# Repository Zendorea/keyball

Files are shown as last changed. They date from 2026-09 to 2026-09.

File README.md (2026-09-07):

# Keyball61 Wireless (PMW3610 / nice!nano / ZMK)

A fork of [Yowkees/keyball](https://github.com/Yowkees/keyball) for converting a
**Keyball61** (holykeebs Keyball61 rev2) to a **fully wireless** build:
**nice!nano v2 + ZMK**, with the power-hungry PMW3360 trackball sensor replaced by
the low-power **PMW3610**.

This fork holds the **hardware** side of that conversion — the custom PMW3610
sensor daughterboard. The **firmware** (ZMK) lives in a separate repo.

## What's here

- **[`keyball61_wireless/pmw3610_daughterboard/`](keyball61_wireless/pmw3610_daughterboard/)**
  — the PMW3610 trackball daughterboard: KiCad source, reproducible build
  pipeline, DRC-clean gerbers (ordered from PCBway), BOM, and full design notes.
  A drop-in replacement for the stock Keyball61 ball-reader board that keeps the
  original 7-pin connector and adds a MOTION interrupt line. **See its README.**
- **`keyball61/`** — the upstream Yowkees Keyball61 hardware design data (kept for
  reference: case, PCB, dimensions the daughterboard indexes to).

## Firmware (separate repo)

The wireless ZMK config is **`zmk-config-keyball61-wireless`** (standalone, as ZMK
configs must be). Trackball on `&spi1`: SCK P1.13, SDIO P0.10 (3-wire), CS P0.09,
MOTION P1.11, 2 MHz — based on the proven `tangbonze/zmk-config-Keyball61`.

## Project status

- ✅ Daughterboard: designed, DRC-clean, gerbers ordered (PCBway, ENIG, 1.0 mm)
- ✅ Parts sourced: PMW3610+LM18-LSI (AliExpress), passives/LDO (LCSC), 34 mm ball
- ✅ ZMK config: built (separate repo)
- ⬜ Assemble + flash when hardware arrives
- ⬜ (optional) main-board fork: nice!nano + nice!view

## Credits

Base keyboard design © [Yowkees / Keyball](https://github.com/Yowkees/keyball)
(see `LICENSE`). PMW3610 reference designs: siderakb / badjeff. Kit: holykeebs.

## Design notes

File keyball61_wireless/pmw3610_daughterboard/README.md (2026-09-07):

# PMW3610 Trackball Daughterboard — Keyball61 Wireless

Drop-in replacement for the stock Keyball61 PMW3360 ball-reader board, redesigned
for the low-power **PMW3610** sensor on a **nice!nano / ZMK** wireless build.
Keeps the stock Keyball **7-pin** connector at the exact original positions (drops
into a stock Keyball main board) and adds a **separate MOTION solder hole** so ZMK
can run the sensor interrupt-driven for best battery life.

**Status: final, DRC-clean, gerbers ordered from PCBway.**

## Board summary
- **23.0 × 25.0 mm**, 2-layer, **1.0 mm**, ENIG. U-shaped outline with a lens slot
  open to the top edge, sized to the **LM18-LSI** lens body.
- **PMW3610 optical center** at the original ball-facing position; connector +
  sensor share the X=11.0 mm centerline (ball centers on the IC via the stock
  Keyball cage).
- **7-pin connector** (CK·IO·G·V·G·CS·RST) at exact stock 2.54 mm positions +
  a separate **MOT** solder hole on the same pitch.
- Full PMW3610 support: **TLV74318** 1.8 V LDO + charge-pump/decoupling caps +
  NRESET & MOTION pull-ups. Solid B.Cu GND pour with stitching vias.
- DRC: **0 unrouted / 0 unconnected / 0 electrical / 0 hole-clearance**
  (5 non-fatal courtyard-overlap advisories — not fab-blocking).

## Files
| File | What it is |
|---|---|
| `DESIGN.md` | Full design spec: optics Z-stack, connector, MOTION, datasheet notes. |
| `BOM.csv` | As-built bill of materials with LCSC part numbers + cap-to-pin mapping. |
| `pmw3610_daughterboard.kicad_pcb` / `.kicad_pro` | Final routed board + project. |
| `pmw3610_daughterboard.kicad_dru` | Custom design rules (0.15 mm edge clearance). |
| `pmw3610_kb.pretty/` | The 3 custom footprints used: PMW3610 (siderakb), 7-pin connector, MOTION pad. |
| `fp-lib-table` | Resolves the local footprint lib on open. |
| `gerbers/` + `pmw3610_daughterboard_gerbers.zip` | Fab package (PCBway-ready): 7 gerbers + separate PTH/NPTH Excellon drills. |
| `drc.json` | Latest DRC report. |
| `board_final.png` / `board_top.png` / `board_bot.png` | Renders. |

## Reproducible build pipeline (KiCad 10 pcbnew + Freerouting 2.4.1)
Run in order (system `python3` with `pcbnew`, except footprints which use kiutils):
```
make_footprints_v2.py   -> custom footprints (sensor, 7-pin conn, MOTION pad)
build_board_22x25.py    -> place + net + design rules
export_dsn.py           -> Specctra DSN
Freerouting (headless, -mt 1, --router.via_costs=30, -inc GND)
import_ses.py           -> import routed session
pour_gnd.py             -> B.Cu GND pour (solid pad connection)
finish_22x25.py         -> GND stitching vias; fill zones last
kicad-cli pcb drc / export gerbers,drill
```

## Parts sourcing
- **Sensor + lens:** PMW3610DM-**SUDU** + **LM18-LSI** as a SET on AliExpress
  (not stocked at LCSC/Digikey). Match the lens (LM18-LSI) — avoid the 3360/LM19.
- **Passives + LDO + header:** LCSC (see `BOM.csv` for exact part numbers).
- **Ball:** 34 mm (Perixx PERIPRO-303 / SANWA).

## Firmware
Wireless ZMK config lives in a separate repo (`zmk-config-keyball61-wireless`):
trackball on `&spi1` — SCK P1.13, SDIO P0.10 (3-wire), CS P0.09, MOTION P1.11,
2 MHz. See that repo's README.

## Verify before assembly
- Sensor/lens standoff vs your trackball housing (base-plate sets focus, not PCB thickness).
- Continuity-check the sensor pins (esp. SCLK) after soldering — the most common DIY failure.

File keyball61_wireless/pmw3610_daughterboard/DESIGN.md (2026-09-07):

# PMW3610 Trackball Daughterboard — Keyball61 Wireless (nice!nano / ZMK)

Purpose-built PMW3610 replacement for the stock Keyball61 PMW3360 ball-reader
board, for a nice!nano/ZMK wireless build (low power). Datasheet-faithful optical
mounting. DRC-clean.

## Final specs
- Outline: 23.0 x 25.0 mm (original 22x25 + 1mm on the right so the MOTION hole
  sits on the connector's 2.54mm pitch at full pad size). 1.0mm thick, 2-layer.
- Optics: lens slot open to the top edge, sized to the LM18-LSI lens body
  (8.25 x 12.9mm), between the sensor pin columns. No PCB lens-alignment hole:
  the LM18-LSI guide posts lock into the sensor package, not the PCB (per the
  PMW3610 datasheet Fig 5 and the siderakb/badjeff reference boards).
  PMW3610 sensor optical center at original ball-facing position.
- Connector: stock Keyball 7-pin (SCLK,SDIO,GND,VCC,GND,NCS,NRESET) at the EXACT
  original 2.54mm-pitch positions -> drops into a stock Keyball main board.
- MOTION: separate solder hole (MOT) on the same 2.54mm pitch as the connector,
  same 1.5mm pad / 0.9mm drill. Wire it to a spare nice!nano GPIO (P0.31) on the
  stock board, or route it as a trace on a forked main board.
- Full PMW3610 support circuit: TLV74318 1.8V LDO (U2) + charge-pump/decoupling
  caps + NRESET pull-up. All parts ABOVE the connector line (nothing fouls the
  90-degree main-board joint). GND ground plane on B.Cu.
- Placement per IPC-7351/Eurocircuits: 0603 >=2.8mm pitch, 0805 >=3.2mm.

## Datasheet Z-stack (PixArt, saved in ../../../pmw3610_datasheets/)
- Ball surface -> lens reference plane = 2.4mm typ (2.2/2.6 min/max), +/-0.2mm DOF.
- Ball surface -> sensor pin reference plane (PCB top copper) = 8.35mm typ.
- PCB thickness does NOT set focus (lens indexes to the pin plane); 1.0mm chosen
  for lens/ball clearance. Verify base-plate/housing standoff at assembly.

## Reproducible build pipeline (KiCad 10 pcbnew + Freerouting 2.4.1)
  make_footprints_v2.py  -> custom footprints (sensor, 7-pin conn, MOTION pad, lens)
  build_board_22x25.py   -> place + net + design rules (pcbnew)
  export_dsn.py          -> Specctra DSN
  Freerouting (headless, -mt 1, --router.via_costs=30, -inc GND for pour route)
  import_ses.py          -> import routed session
  pour_gnd.py            -> B.Cu GND pour (solid pad connection)
  finish_22x25.py        -> GND stitching vias; fill zones last
  kicad-cli pcb drc / export gerbers,drill

## DRC status
0 unrouted, 0 unconnected, 0 electrical violations. 5 courtyard_overlap
advisories remain (IPC keep-out for rework room, NOT fab-blocking; JLCPCB/PCBway
build fine). See board_final.png.

## Fab (PCBway)
2-layer, 1.0mm, ENIG, qty 5. Upload pmw3610_daughterboard_gerbers.zip.

## Verify before ordering
1. Sensor/lens standoff vs your trackball housing (base-plate sets focus).
2. Trackball connector CS/IRQ vs your holykeebs rev2 PCB silk (rev1≈rev2).

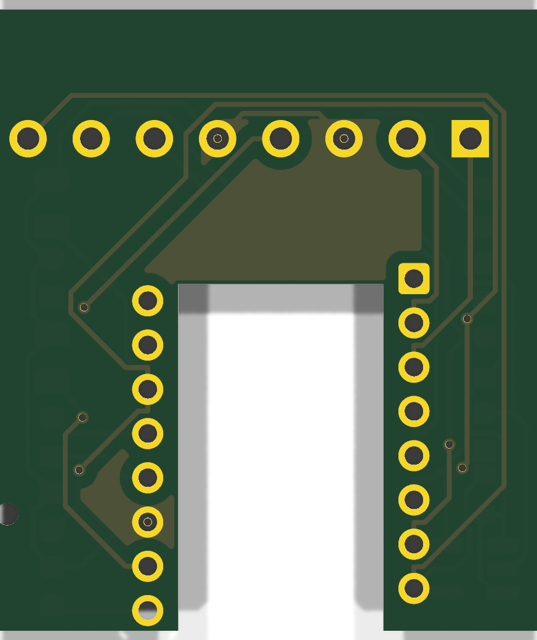
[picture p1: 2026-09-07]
keyball61_wireless/pmw3610_daughterboard/board_bot.png

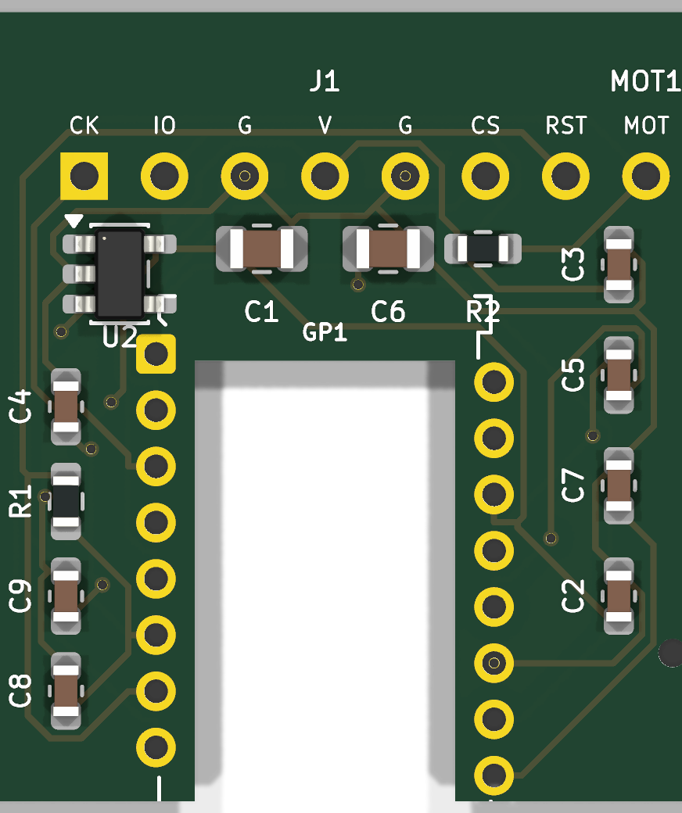
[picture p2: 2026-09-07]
keyball61_wireless/pmw3610_daughterboard/board_final.png

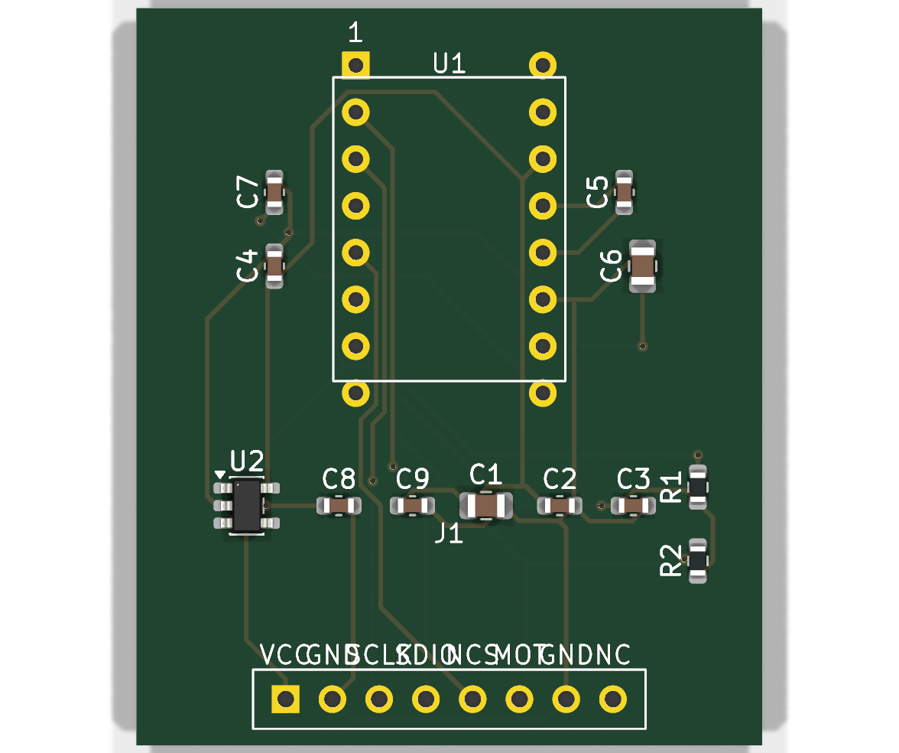
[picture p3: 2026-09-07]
keyball61_wireless/pmw3610_daughterboard/board_top.png

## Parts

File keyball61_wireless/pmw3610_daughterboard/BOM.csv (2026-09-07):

Ref | Value | Footprint | LCSC | Qty | Pin/Net | Notes
U1 | PMW3610DM-SUDU | pmw3610_kb:PMW3610DM-SUDU-siderakb |  | 1 | - | Optical sensor; buy as a SET with the LM18-LSI lens (AliExpress). Not stocked at LCSC/Digikey.
LENS | LM18-LSI | - |  | 1 | - | PixArt lens for PMW3610; bundled with U1.
U2 | TLV74318PDBVR | SOT-23-5 | C485152 | 1 | VCC->+1V8 | 1.8V fixed LDO (core rail).
C1 | 3.3uF/25V X5R | C_0603_1608Metric | C342962 | 1 | VDD (+1V8) | 1.8V core bulk reservoir.
C2 | 100nF X7R | C_0603_1608Metric | C14663 | 1 | VDD (+1V8) | 1.8V core HF decouple.
C3 | 100nF X7R | C_0603_1608Metric | C14663 | 1 | VDDIO (VCC) | I/O supply decouple.
C4 | 100nF X7R | C_0603_1608Metric | C14663 | 1 | VDD (+1V8) | Additional core decouple.
C5 | 10nF X7R | C_0603_1608Metric | C57112 | 1 | CP<->CN | Charge-pump flying cap.
C6 | 10uF X5R | C_0805_2012Metric | C15850 | 1 | PASS_T | Internal-regulator bypass reservoir.
C7 | 10nF X7R | C_0603_1608Metric | C57112 | 1 | VCP | Charge-pump output decouple.
C8 | 1uF/25V X7R | C_0603_1608Metric | C29936 | 1 | VCC (LDO IN) | LDO input cap.
C9 | 1uF/25V X7R | C_0603_1608Metric | C29936 | 1 | +1V8 (LDO OUT) | LDO output cap.
R1 | 10k | R_0603_1608Metric | C25804 | 1 | NRESET<->VCC | NRESET pull-up to 3.3V.
R2 | 10k | R_0603_1608Metric | C25804 | 1 | MOTION<->VCC | MOTION pull-up (populated; hardens the MOTION line alongside the nice!nano internal pull-up).
J1 | Conn_Keyball_7pin | pmw3610_kb:Conn_Keyball_7pin_stock |  | 1 | - | Stock Keyball 7-pin 2.54mm connector: CK/IO/G/V/G/CS/RST.
MOT1 | MOTION | pmw3610_kb:MOTION_solder_pad |  | 1 | MOTION | Separate MOTION solder hole on 2.54mm pitch; wire to a spare nice!nano GPIO.

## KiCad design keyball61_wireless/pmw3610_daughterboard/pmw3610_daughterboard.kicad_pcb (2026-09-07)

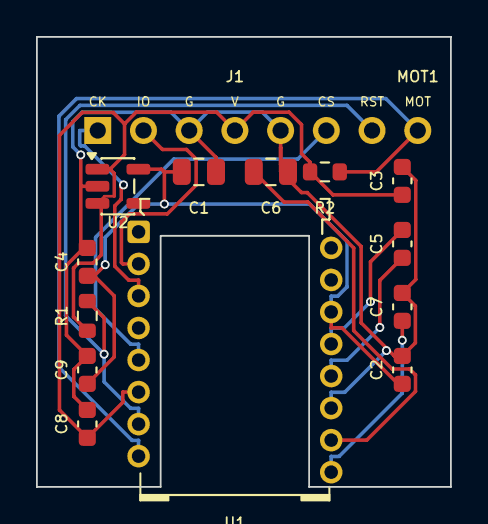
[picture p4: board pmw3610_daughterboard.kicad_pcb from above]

Board: 2 copper layers, 23.0 x 25.0 mm, 15 parts (0 on the bottom side), 12 nets.

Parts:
C1: 3.3uF; C_0805_2012Metric
C2, C3, C4: 100nF; C_0603_1608Metric
C5, C7: 10nF; C_0603_1608Metric
C6: 10uF; C_0805_2012Metric
C8, C9: 1uF; C_0603_1608Metric
J1: Conn_Keyball_7pin; Conn_Keyball_7pin_stock
MOT1: MOTION; MOTION_solder_pad
R1, R2: 10k; R_0603_1608Metric
U1: PMW3610DM-SUDU; PMW3610DM-SUDU-siderakb
U2: TLV74318PDBVR; SOT-23-5

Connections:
+1V8: C1.1, C2.1, C4.1, C9.1, U1.14, U2.5
CN: C5.2, U1.13
CP: C5.1, U1.12
GND: C1.2, C2.2, C3.2, C4.2, C6.2, C7.2, C8.2, C9.2, J1.3, J1.5, U1.11, U2.2
MOTION: MOT1.1, R2.2, U1.8
NCS: J1.6, U1.5
NRESET: J1.7, R1.2, U1.7
PASST: C6.1, U1.10
SCLK: J1.1, U1.3
SDIO: J1.2, U1.2
VCC: C3.1, C8.1, J1.4, R1.1, R2.1, U1.6, U2.1, U2.3
VCP: C7.1, U1.9

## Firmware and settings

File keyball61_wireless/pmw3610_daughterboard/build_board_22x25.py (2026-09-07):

#!/usr/bin/env python3
"""22x25mm ORIGINAL-SIZE variant. Exact original slot/sensor/connector positions.
All 14 support parts packed front-side into the side columns + the thin bottom
strip below the connector. GND connects via pour + stitching vias (not traces).
Tests whether the original footprint routes now that the iterator bug is fixed."""
import os, pcbnew
HERE = os.path.dirname(os.path.abspath(__file__))
PRETTY = os.path.join(HERE, "pmw3610_kb.pretty")
STOCK = "/usr/share/kicad/footprints"
OUT = os.path.join(HERE, "pmw3610_daughterboard.kicad_pcb")
W, H = 23.0, 25.0
def mm(v): return pcbnew.FromMM(v)
NETS = ["GND","VCC","+1V8","SCLK","SDIO","NCS","MOTION","NRESET","CP","CN","VCP","PASST"]

# ORIGINAL positions (bottom-left origin): sensor columns X5.65/16.35 center Y17.5;
# connector Y5.2. LENS CUTOUT (datasheet LM18-LSI body 12.9 x 8.25mm) drops through
# the board between the pin columns, centered on the sensor optical center.
# Board thickness = 1.0mm (set post-build via text patch). Guide-post holes Ø0.9mm.
# Cutout: width 8.25 (X, between columns 5.65<->16.35), length 12.9 (Y), centered (11,17.5).
LENS_W, LENS_L = 8.25, 12.9
LCX, LCY = 11.0, 17.5
SL, SR = LCX-LENS_W/2, LCX+LENS_W/2      # 6.875, 15.125
SB, ST = LCY-LENS_L/2, LCY+LENS_L/2      # 11.05, 23.95  (interior cutout, not open to edge)
SENS_X, SENS_Y = 11.0, 17.0
CONN_Y = 5.2
U1_NETS = {"2":"SDIO","3":"SCLK","5":"NCS","6":"VCC","7":"NRESET","8":"MOTION",
           "9":"VCP","10":"PASST","11":"GND","12":"CP","13":"CN","14":"+1V8"}
CONN_NET = {"1":"SCLK","2":"SDIO","3":"GND","4":"VCC","5":"GND","6":"NCS","7":"NRESET"}

# ALL support parts ABOVE the connector (Y>5.5) so NOTHING sits below the connector
# line where it would foul the main board at the 90-degree joint. Parts live in the
# left column (X~3) and right column (X~19.5), flanking the lens slot + sensor.
SUPPORT = [
    # RULE-BASED (IPC/Eurocircuits): 0603 pitch >=2.7mm, 0805 >=3.2mm, edge gap >=0.25mm.
    # Front top-side: sensor + LDO + charge-pump/decoupling caps that must hug pins.
    # Bulk 0805s (C1,C6) and DNP R2 pushed to BACK layer to relieve front density.
    #
    # LEFT column (X~2.8), 0603 @ 2.8mm pitch, U2 (LDO) at far bottom
    # LEFT column caps stacked HIGH (Y 12-24, beside U1 left pins); U2 in the
    # U1-free bottom band (Y~8.5, below U1's pin columns, above the connector).
    ("C4","Capacitor_SMD","C_0603_1608Metric", 2.8, 12.5, 90, "100nF","F"),   # VDD bulk
    ("R1","Resistor_SMD","R_0603_1608Metric",  2.8, 15.5, 90, "10k","F"),     # NRESET pull
    ("C9","Capacitor_SMD","C_0603_1608Metric", 2.8, 18.5, 90, "1uF","F"),     # LDO in
    ("C8","Capacitor_SMD","C_0603_1608Metric", 2.8, 21.5, 90, "1uF","F"),     # LDO out
    ("U2","Package_TO_SOT_SMD","SOT-23-5",     4.5, 8.3,  0,  "TLV74318PDBVR","F"),  # LDO in bottom band, clear of U1
    # RIGHT column (X~20.3), 0603 @ 3.0mm pitch; charge-pump/analog caps hug sensor
    ("C3","Capacitor_SMD","C_0603_1608Metric", 20.3, 8.0,  90, "100nF","F"),   # VDDIO decouple
    ("C5","Capacitor_SMD","C_0603_1608Metric", 20.3, 11.5, 90, "10nF","F"),    # CP-CN, hugs U1.12/13
    ("C7","Capacitor_SMD","C_0603_1608Metric", 20.3, 15.0, 90, "10nF","F"),    # VCP, hugs U1.9
    ("C2","Capacitor_SMD","C_0603_1608Metric", 20.3, 18.5, 90, "100nF","F"),   # +1V8 decouple
    # BACK side (under the pins): bulk 0805s + DNP MOTION pull-up. Above connector,
    # so they don't foul the 90-degree main-board joint. Back-side = shortest loop.
    ("C1","Capacitor_SMD","C_0805_2012Metric", 9.0,  7.5, 0, "3.3uF","F"),   # +1V8 bulk, band below sensor pins
    ("C6","Capacitor_SMD","C_0805_2012Metric", 13.0, 7.5, 0, "10uF","F"),    # PASST bulk, band below sensor pins
    ("R2","Resistor_SMD","R_0603_1608Metric",  16.0, 7.5, 0, "10k","F"),      # MOTION pull(DNP)
]
SUP_NETS = {
    "U2":{"1":"VCC","2":"GND","3":"VCC","5":"+1V8"},
    "C8":{"1":"VCC","2":"GND"}, "C9":{"1":"+1V8","2":"GND"},
    "C1":{"1":"+1V8","2":"GND"},"C3":{"1":"VCC","2":"GND"},
    "C2":{"1":"+1V8","2":"GND"},"C5":{"1":"CP","2":"CN"},
    "C6":{"1":"PASST","2":"GND"},"C7":{"1":"VCP","2":"GND"},
    "C4":{"1":"+1V8","2":"GND"},"R1":{"1":"VCC","2":"NRESET"},
    "R2":{"1":"VCC","2":"MOTION"},
}

def main():
    board = pcbnew.BOARD()
    for n in NETS:
        if board.FindNet(n) is None: board.Add(pcbnew.NETINFO_ITEM(board, n))
    ds = board.GetDesignSettings()
    ds.m_TrackMinWidth=mm(0.15); ds.m_MinClearance=mm(0.15)
    ds.m_MinThroughDrill=mm(0.3); ds.m_ViasMinSize=mm(0.5)
    ds.m_CopperEdgeClearance=mm(0.15)
    try: ds.SetBoardThickness(mm(1.0))   # datasheet/ufan: 1.0mm for ball-facing PMW3610
    except Exception as e: print("thick note:", e)
    try:
        sev=ds.m_DRCSeverities; sev["courtyards_overlap"]=pcbnew.SEVERITY_IGNORE
    except Exception as e: print("sev",e)
    try:
        d=board.GetAllNetClasses().get("Default")
        if d: d.SetTrackWidth(mm(0.2)); d.SetViaDiameter(mm(0.5)); d.SetViaDrill(mm(0.3)); d.SetClearance(mm(0.15))
    except Exception as e: print("nc",e)
    def code(n): return board.FindNet(n).GetNetCode()
    def edge(x0,y0,x1,y1):
        s=pcbnew.PCB_SHAPE(board); s.SetShape(pcbnew.SHAPE_T_SEGMENT)
        s.SetStart(pcbnew.VECTOR2I(mm(x0),mm(y0))); s.SetEnd(pcbnew.VECTOR2I(mm(x1),mm(y1)))
        s.SetLayer(pcbnew.Edge_Cuts); s.SetWidth(mm(0.1)); board.Add(s)
    # full outline with a top-OPEN lens slot (sized to LM18-LSI body, opens toward
    # the ball at the top edge). Open slot leaves the routing channel usable, unlike
    # a fully-enclosed hole -- this is what the original Keyball board does.
    edge(0,0,W,0); edge(W,0,W,H)          # bottom, right
    edge(W,H,SR,H)                         # top-right segment (to slot right wall)
    edge(SR,H,SR,SB)                       # slot right wall down
    edge(SR,SB,SL,SB)                      # slot bottom
    edge(SL,SB,SL,H)                       # slot left wall up
    edge(SL,H,0,H)                         # top-left segment
    edge(0,H,0,0)                          # left
    # guide-post hole (Ø0.9mm NPTH) below the slot on the optical axis
    def npth(x,y,d=0.9):
        fp=pcbnew.FOOTPRINT(board)
        pad=pcbnew.PAD(fp); pad.SetAttribute(pcbnew.PAD_ATTRIB_NPTH)
        pad.SetShape(pcbnew.PAD_SHAPE_CIRCLE); pad.SetSize(pcbnew.VECTOR2I(mm(d),mm(d)))
        pad.SetDrillSize(pcbnew.VECTOR2I(mm(d),mm(d)))
        pad.SetPosition(pcbnew.VECTOR2I(mm(x),mm(y)))
        pad.SetLayerSet(pad.UnplatedHoleMask())
        fp.Add(pad); fp.SetPosition(pcbnew.VECTOR2I(mm(x),mm(y)))
        board.Add(fp)
    #npth(LCX, SB-0.9)   # guide post just below the slot
    # (No lens-alignment keepout: no PCB lens holes are needed — see finish_22x25.py.)
    def place(ref,libpath,entry,x,y,rot,value,padnets=None,back=False):
        fp=pcbnew.FootprintLoad(libpath,entry)
        if fp is None: raise RuntimeError(f"missing {libpath}:{entry}")
        fp.SetReference(ref); fp.SetValue(value)
        fp.SetPosition(pcbnew.VECTOR2I(mm(x),mm(y)))
        if rot: fp.SetOrientationDegrees(rot)
        if back: fp.Flip(fp.GetPosition(), False)
        board.Add(fp)
        gi=fp.GraphicalItems()
        for k in range(len(gi)):
            if gi[k].GetLayer()==pcbnew.Edge_Cuts: gi[k].SetLayer(pcbnew.Dwgs_User)
        for pad in fp.Pads():
            net=(padnets or {}).get(pad.GetName())
            if net: pad.SetNetCode(code(net))
        # shrink the reference-designator silk so labels don't overlap/clutter
        try:
            rt=fp.Reference()
            rt.SetTextSize(pcbnew.VECTOR2I(mm(0.6), mm(0.6)))
            rt.SetTextThickness(mm(0.1))
            # top-band parts: put their ref label BELOW the part (clear of connector)
            if ref in ("U2","C1","C6","R2"):
                rt.SetPosition(pcbnew.VECTOR2I(mm(x), mm(y+2.0)))
        except Exception: pass
    place("U1", PRETTY, "PMW3610DM-SUDU-siderakb", SENS_X, SENS_Y, 90, "PMW3610DM-SUDU", U1_NETS)
    place("J1", PRETTY, "Conn_Keyball_7pin_stock", 11.0, CONN_Y, 0, "Conn_Keyball_7pin", CONN_NET)
    # separate MOTION solder pad near U1 pin8 (top-right area) for the wire
    place("MOT1", PRETTY, "MOTION_solder_pad", 21.16, 5.2, 0, "MOTION", {"1":"MOTION"})
    for ref,lib,entry,x,y,rot,value,side in SUPPORT:
        place(ref, os.path.join(STOCK,lib+".pretty"), entry, x, y, rot, value, SUP_NETS.get(ref), back=(side=="B"))
    board.Save(OUT)
    print(f"saved {OUT} | 22x25 1.0mm, lens cutout X[{SL:.2f},{SR:.2f}] Y[{SB:.2f},{ST:.2f}], sensor({SENS_X},{SENS_Y}) conn Y={CONN_Y}")

if __name__ == "__main__":
    main()

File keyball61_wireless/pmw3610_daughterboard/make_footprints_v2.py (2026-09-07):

#!/usr/bin/env python3
"""
Footprint library for the PMW3610 Keyball daughterboard (real 22x25mm geometry).

Conn_Keyball_8pin_v2 : matches the ORIGINAL Keyball ball_sensor 7-pin connector
  EXACTLY (7 round 1.5mm pads at 2.54mm pitch, centered), then adds an 8th pad
  (MOTION) to the LEFT of pin 1 keeping the original 7 in place -> still mates a
  stock Keyball main board on pins 1-7.

  Original pad X (board-centered, X=11.0 is board center, board is 22mm wide):
    p1..p7 at X = 3.38,5.92,8.46,11.00,13.54,16.08,18.62  (from left edge)
  In footprint-local coords centered on the connector midpoint (X=11.0):
    p1..p7 at -7.62,-5.08,-2.54,0,+2.54,+5.08,+7.62
  MOTION p8 added at -10.16 (left of p1).

PMW3610_SMD : the PMW3610DM-SUDU as a molded DIP mounted ball-facing, with the
  LM18-LSI lens envelope marked. Uses the community 2.54mm/1.78mm DIP pad pattern.
  (Lens sits on TOP of the IC facing the ball; NO board cutaway.)
"""
import os
from kiutils.footprint import (Footprint, Pad, DrillDefinition, FpText, FpLine,
                               Attributes)
from kiutils.items.common import Position, Effects, Font

OUT = os.path.join(os.path.dirname(__file__), "pmw3610_kb.pretty")
os.makedirs(OUT, exist_ok=True)


def th_pad(number, x, y, drill, size, shape="circle"):
    return Pad(number=str(number), type="thru_hole", shape=shape,
               position=Position(x, y), size=Position(size, size),
               drill=DrillDefinition(diameter=drill), layers=["*.Cu", "*.Mask"])


def line(fp, x0, y0, x1, y1, layer="F.SilkS", w=0.12):
    fp.graphicItems.append(FpLine(start=Position(x0, y0), end=Position(x1, y1),
                                  layer=layer, width=w))


def rect(fp, w, h, cx, cy, layer="F.SilkS", width=0.12):
    x0, y0, x1, y1 = cx-w/2, cy-h/2, cx+w/2, cy+h/2
    line(fp, x0, y0, x1, y0, layer, width); line(fp, x1, y0, x1, y1, layer, width)
    line(fp, x1, y1, x0, y1, layer, width); line(fp, x0, y1, x0, y0, layer, width)


def txt(fp, t, s, x, y, layer, h=0.6):
    fp.graphicItems.append(FpText(type=t, text=s, position=Position(x, y),
                                  layer=layer,
                                  effects=Effects(font=Font(height=h, width=h, thickness=h*0.15))))


def new_fp(entry, kind="through_hole"):
    fp = Footprint(); fp.libraryNickname = "pmw3610_kb"; fp.entryName = entry
    fp.generator = "kiutils"; fp.layer = "F.Cu"
    fp.attributes = Attributes(type=kind)
    txt(fp, "reference", "REF**", 0, -3, "F.SilkS")
    txt(fp, "value", entry, 0, 3, "F.Fab")
    return fp


def make_conn7_stock():
    """EXACT stock Keyball 7-pin connector: 7 pads @2.54mm, centered. No MOTION
    pin (that's a separate solder hole). Drops into a stock Keyball main board."""
    fp = new_fp("Conn_Keyball_7pin_stock")
    xs = {"1": -7.62, "2": -5.08, "3": -2.54, "4": 0.0, "5": 2.54, "6": 5.08, "7": 7.62}
    # stock Keyball J2 net order: P1/P2/P6/P7 data, P3/P5 GND, P4 VCC.
    nets = {"1":"CK","2":"IO","3":"G","4":"V","5":"G","6":"CS","7":"RST"}
    for num in ["1","2","3","4","5","6","7"]:
        fp.pads.append(th_pad(num, xs[num], 0.0, drill=0.9, size=1.5,
                              shape="rect" if num=="1" else "circle"))
        txt(fp, "user", nets[num], xs[num], -1.6, "F.SilkS", h=0.5)
    return fp


def make_motion_pad():
    """Single labeled through-hole solder pad for the MOTION wire to a nice!nano
    GPIO. Used on both the stock-board build (flying wire) and the forked main
    board (routed trace to the pad)."""
    fp = new_fp("MOTION_solder_pad")
    fp.pads.append(th_pad("1", 0.0, 0.0, drill=0.9, size=1.5, shape="circle"))
    txt(fp, "user", "MOT", 0, -1.6, "F.SilkS", h=0.5)
    return fp


def make_conn8_v2():
    fp = new_fp("Conn_Keyball_8pin_v2")
    pitch = 2.54
    # original 7 at -7.62..+7.62, MOTION added at -10.16
    xs = {"8": -9.2, "1": -7.62, "2": -5.08, "3": -2.54, "4": 0.0,
          "5": 2.54, "6": 5.08, "7": 7.62}
    # Real Keyball J2 order (from main-board netlist): P3/P5=GND, P4=VCC,
    # P1/P2/P6/P7 = the 4 data lines. PMW3610 is 3-wire, so we assign:
    #   P1=SCLK  P2=SDIO  P6=NCS  P7=NRESET   (P4=VCC, P3/P5=GND)  P8=MOTION(new)
    nets = {"1":"SCLK","2":"SDIO","3":"GND","4":"VCC","5":"GND",
            "6":"NCS","7":"NRESET","8":"MOT"}
    for num in ["1","2","3","4","5","6","7","8"]:
        fp.pads.append(th_pad(num, xs[num], 0.0, drill=0.9, size=1.5,
                              shape="rect" if num == "1" else "circle"))
        txt(fp, "user", nets[num], xs[num], -1.8, "F.SilkS")
    rect(fp, 8*pitch + 2.5, 3.0, 0, 0, layer="F.SilkS")
    txt(fp, "user", "P1-7 match stock Keyball J2; P8=MOTION (added)", 0, 2.6, "F.Fab")
    return fp


def make_pmw3610_smd():
    # 16-pin DIP, 2 rows 1.78mm pitch (community footprint), rows ~10.7mm apart.
    # Mounted ball-facing; LM18-LSI lens envelope 8.26 x 13.10 mm marked on F.Fab.
    fp = new_fp("PMW3610DM-SUDU-SMD", kind="through_hole")
    pitch = 1.78
    row_dx = 10.7/2.0
    y0 = -(7*pitch)/2.0
    for i in range(8):
        n = i+1
        fp.pads.append(th_pad(n, -row_dx, y0+i*pitch, drill=0.7, size=1.2,
                              shape="rect" if n == 1 else "circle"))
    for i in range(8):
        n = 16-i
        fp.pads.append(th_pad(n, +row_dx, y0+i*pitch, drill=0.7, size=1.2))
    # sensor body + lens envelope
    rect(fp, 12.0, 10.9+2*pitch, 0, 0, layer="F.Fab")
    rect(fp, 8.26, 13.10, 1.5, 0, layer="F.Fab")   # LM18-LSI lens envelope
    txt(fp, "user", "LM18-LSI lens (ball-facing, on TOP of IC)", 0, 12, "F.Fab")
    txt(fp, "user", "optical center", 1.5, 0, "F.Fab")
    txt(fp, "user", "1", -row_dx, y0-1.6, "F.SilkS")
    return fp


def save(fp, name):
    p = os.path.join(OUT, name + ".kicad_mod")
    fp.to_file(p); Footprint.from_file(p)
    print("wrote+validated", p)


if __name__ == "__main__":
    save(make_conn8_v2(), "Conn_Keyball_8pin_v2")
    save(make_conn7_stock(), "Conn_Keyball_7pin_stock")
    save(make_motion_pad(), "MOTION_solder_pad")
    save(make_pmw3610_smd(), "PMW3610DM-SUDU-SMD")
    print("done")

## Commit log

2026-09-06 Add PMW3610 wireless trackball daughterboard for Keyball61
    Purpose-built PMW3610 (low-power) replacement for the stock PMW3360
    ball-reader board, for a nice!nano/ZMK wireless build. 8-pin connector
    carries a MOTION interrupt line (vs stock 7-pin SPI-only) so ZMK runs
    the sensor interrupt-driven for best battery life.
    - Custom KiCad footprints: PMW3610 16-DIP, 8-pin Keyball connector
    (2.54mm pitch matching stock Mac8_L_7pin geometry + MOTION pad)
    - Placed + fully net-assigned .kicad_pcb (24x32mm, 2-layer); passives
    reference KiCad stock libs. Not auto-routed - route+DRC in KiCad.
    - KiCad netlist, human-readable SCHEMATIC.md, DESIGN.md, BOM.csv
    - Reproducible kiutils generators (make_foot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
    [BOM.csv, pmw3610_daughterboard.kicad_pcb]
2026-09-07 Route PMW3610 daughterboard to DRC-clean fab-ready gerbers
    Rebuilt the board with KiCad's native pcbnew API (replacing the kiutils
    writer, which emitted KiCad-6 track syntax KiCad 10 rejected), auto-routed
    with Freerouting 2.4.1 headless, imported the session, and exported gerbers.
    Result: 0 DRC violations, 0 unconnected items. 14 components, 2-layer,
    34x40mm, GND pour on B.Cu. Fab package zipped for PCBway.
    Pipeline (reproducible):
    - build_board.py : place + net + design rules (pcbnew)
    - export_dsn.py : ExportSpecctraDSN
    - Freerouting : headless auto-route (.dsn -> .ses)
    - import_ses.py : ImportSpecctraSES + zone fill
    - fix_track_width.py : widen any sub-0.25mm trace
    - make_fab.s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
    [pmw3610_daughterboard-B_Cu.gbr, pmw3610_daughterboard-B_Mask.gbr, pmw3610_daughterboard-B_Silkscreen.gbr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]
2026-09-07 Finalize PMW3610 daughterboard: datasheet-faithful, DRC-clean
    23x25mm (orig 22x25 +1mm for on-pitch MOTION hole), 1.0mm, 2-layer.
    - Lens slot sized to LM18-LSI (open to top edge) + guide-post hole
    - Stock 7-pin connector at exact original positions + separate MOTION
    solder hole on the 2.54mm pitch, matched 1.5/0.9mm diameter
    - Full PMW3610 circuit (TLV74318 LDO + charge-pump/decoupling caps),
    all parts above the connector (clears the 90-deg main-board joint)
    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
    [pmw3610_daughterboard-B_Cu.gbr, pmw3610_daughterboard-B_Mask.gbr, pmw3610_daughterboard-B_Silkscreen.gbr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]
2026-09-07 Relocate C1/C6 bulk caps clear of the optic/sensor pins
    Moved the two 0805 bulk caps + MOTION pull-up out of the tight
    sensor-adjacent area into the connector-to-sensor band: ~2mm clearance
    from the sensor pins, well below the lens slot (no Z conflict with the
    LM18-LSI optic). 0 electrical DRC violations; regenerated gerbers.
    [pmw3610_daughterboard-B_Cu.gbr, pmw3610_daughterboard-B_Mask.gbr, pmw3610_daughterboard-B_Silkscreen.gbr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]
2026-09-07 Remove speculative PCB guide-post hole; regenerate fab package
    The GP1 NPTH guide-post hole was both mislocated (a pcbnew pad/footprint
    offset stacked it to the board corner) and unnecessary: per the PMW3610
    datasheet Fig 5 and the LM18-LSI datasheet, the lens guide posts lock into
    the SENSOR PACKAGE, not the PCB. Both siderakb and badjeff reference boards
    have zero lens-alignment holes. Removing it clears the hole-clearance DRC
    errors it caused.
    Board now DRC-clean: 0 unconnected, 0 electrical, 0 hole-clearance (only
    non-fatal courtyard-overlap advisories remain). Regenerated gerbers with a
    clean fab layer set and separate PTH/NPTH Excellon drill files.
    [pmw3610_daughterboard-B_Cu.gbr, pmw3610_daughterboard-B_Mask.gbr, pmw3610_daughterboard-B_Silkscreen.gbr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]
2026-09-07 Fix fab package: include Edge_Cuts outline gerber (was missing)
    The clean re-export used layer name 'Edge_Cuts' (underscore); kicad-cli
    expects 'Edge.Cuts' (dot), so the board-outline layer silently did not
    export. Without it a fab would guess a rectangular boundary and NOT rout
    the lens slot. Corrected layer name; Edge_Cuts.gbr now present and verified
    to contain the slot walls (interior edge at Y=11.05mm).
    [pmw3610_daughterboard-B_Cu.gbr, pmw3610_daughterboard-B_Mask.gbr, pmw3610_daughterboard-Edge_Cuts.gbr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]
2026-09-07 Clean fork to keyball61-only; refresh docs to final board state
    - Remove other keyboards (keyball39/44/46, Keybit8), qmk_firmware, bin/ — this
    fork is now scoped to the Keyball61 wireless conversion.
    - Remove dead daughterboard scratch: old board versions (v1/v2/v3/24x32),
    superseded scripts (make_footprints v1, make_netlist, pour_and_fill,
    fix_track_width, make_fab), stale DRC dumps, unused footprints, and the old
    8-pin SCHEMATIC.md/.net.
    - Rewrite stale READMEs (were 8-pin/24x32/not-routed) to the final state:
    23x25mm 7-pin, DRC-clean, gerbers ordered. Fix DESIGN.md (GP1 removed, 5
    courtyard advisories, ENIG). Regenerate BOM.csv with correct LCSC codes,
    7-pin connector, R2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
    [BOM.csv, Keyball39Case1_Ball_Right_mm.stl, Keyball39Case1_NoBall_Left_mm.stl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]
2026-09-07 Drop committed .kicad_prl (KiCad UI state); gitignore it
